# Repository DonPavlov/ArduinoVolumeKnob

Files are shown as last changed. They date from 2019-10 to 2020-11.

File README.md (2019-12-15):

This is an Arduino Pro Micro Volume Knob following the following example.

https://www.heise.de/select/make/2019/2/1556001541578799

Troubleshooting:
If your Pro Micro does not want to be programmed do the following:

Verify the correct upload port and set it in the platformio.ini file.
(Unplug the device check the which devices are under /dev/tty:
    ls /dev/tty*
And replug the device)

If programming still fails, wait while it is uploading and use something metal and connect RST and GND pin for a short while. This reset should be enough to upload the latest Arduino files onto the Board and should work now after that without an Reset.

PCB Layout
------------------

The PCB itself was designed in KiCaD and has the following design:

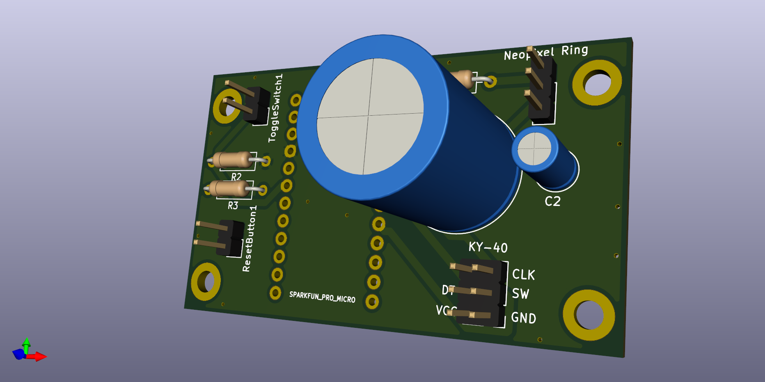
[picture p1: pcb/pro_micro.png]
3dView

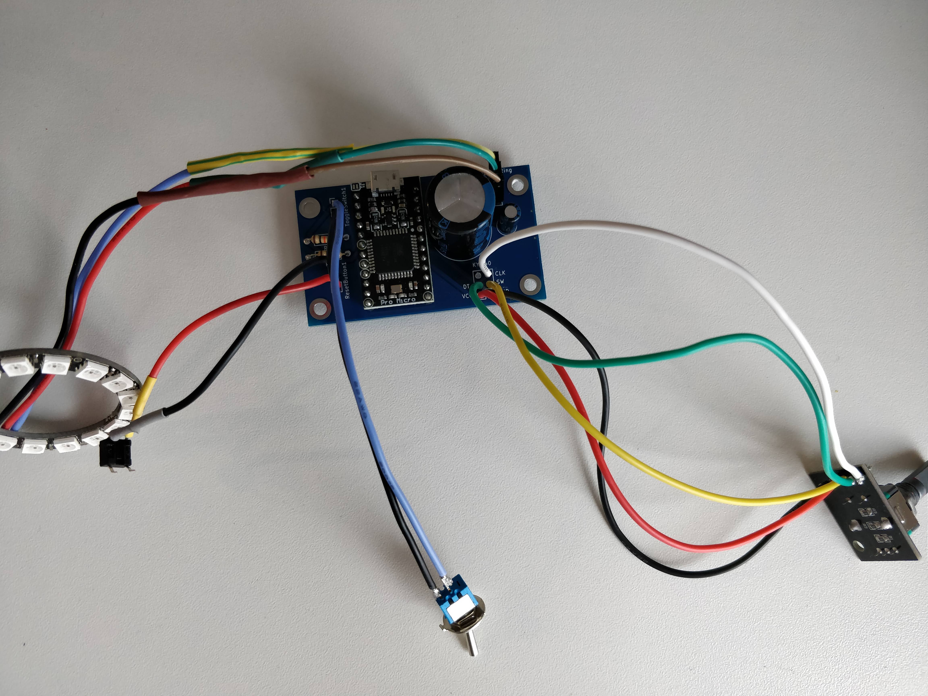
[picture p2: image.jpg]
soldered

schematic

It uses additional features of a possible reset button.
And a free toggle Button to connect and do interesting stuff. (Select in grub the used os to boot or other such things)

TODO
-------------------

* Implement functionality to select windows in grub (arrow down, arrow down, enter) after device was switched on after 5 seconds it will trigger (depends on grub timeout)
    * Do this only if the switch was flipped into the windows position
* Better documentation

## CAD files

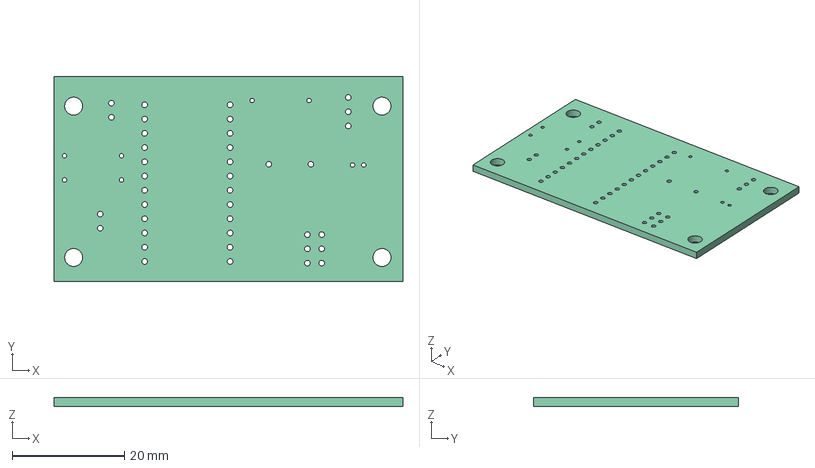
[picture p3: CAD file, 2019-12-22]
pcb/pcbstepup.FCStd
62.2 x 36.5 x 1.60 mm

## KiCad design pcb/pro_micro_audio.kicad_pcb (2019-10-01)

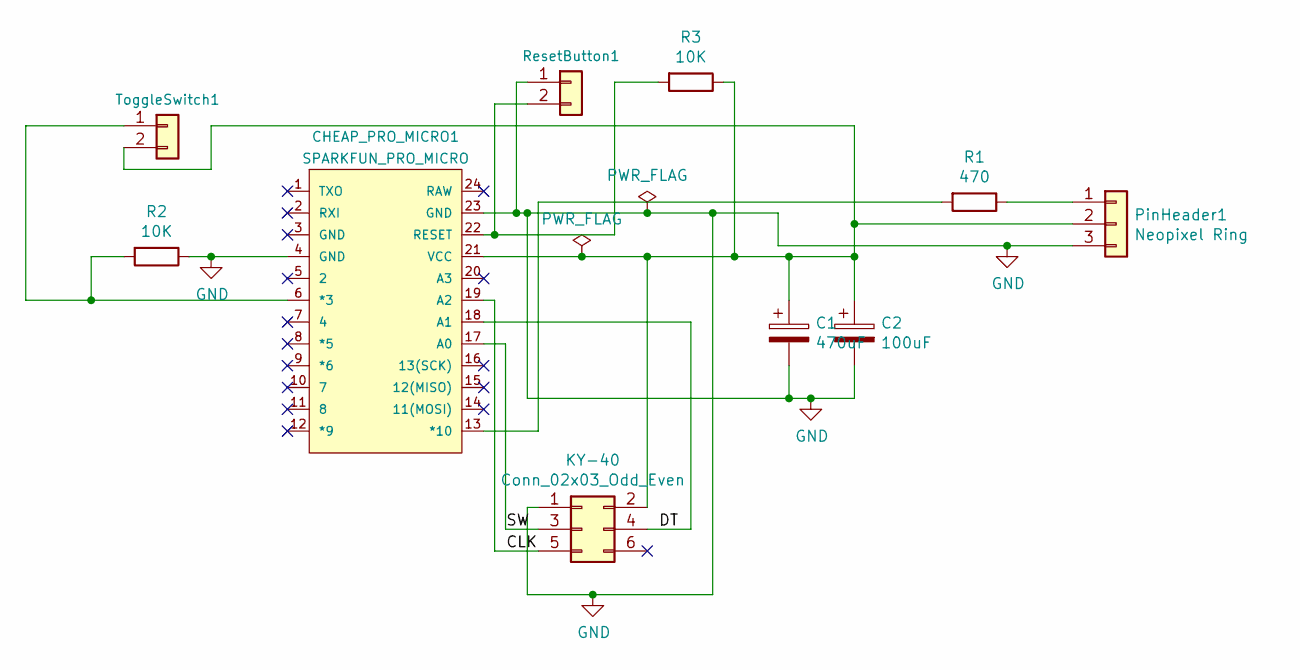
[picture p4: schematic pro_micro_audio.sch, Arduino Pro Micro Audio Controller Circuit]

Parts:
C1: 470uF; C_Radial_D16.0mm_H25.0mm_P7.50mm
C2: 100uF; C_Radial_D5.0mm_H11.0mm_P2.00mm
CHEAP_PRO_MICRO1: SPARKFUN_PRO_MICRO
KY-40: Conn_02x03_Odd_Even; PinHeader_2x03_P2.54mm_Vertical
PinHeader1: Neopixel Ring; PinHeader_1x03_P2.54mm_Vertical
R1: 470; R_Axial_DIN0207_L6.3mm_D2.5mm_P10.16mm_Horizontal
R2, R3: 10K; R_Axial_DIN0207_L6.3mm_D2.5mm_P10.16mm_Horizontal
ResetButton1: Connector_Generic:Conn_01x02; PinHeader_1x02_P2.54mm_Vertical
ToggleSwitch1: Connector_Generic:Conn_01x02; PinHeader_1x02_P2.54mm_Vertical

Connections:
/CLK: CHEAP_PRO_MICRO1.19 (A2), KY-40.5
/DT: CHEAP_PRO_MICRO1.18 (A1), KY-40.4
/SW: CHEAP_PRO_MICRO1.17 (A0), KY-40.3
GND: C1.2, C2.2, CHEAP_PRO_MICRO1.4 (GND), CHEAP_PRO_MICRO1.23 (GND), KY-40.1, PinHeader1.3, R2.1, ResetButton1.1
unnamed: C1.1, C2.1, CHEAP_PRO_MICRO1.21 (VCC), KY-40.2, PinHeader1.2, R3.1, ToggleSwitch1.2
unnamed: CHEAP_PRO_MICRO1.6 (*3), R2.2, ToggleSwitch1.1
unnamed: CHEAP_PRO_MICRO1.13 (*10), R1.2
unnamed: CHEAP_PRO_MICRO1.22 (RESET), R3.2, ResetButton1.2
unnamed: PinHeader1.1, R1.1

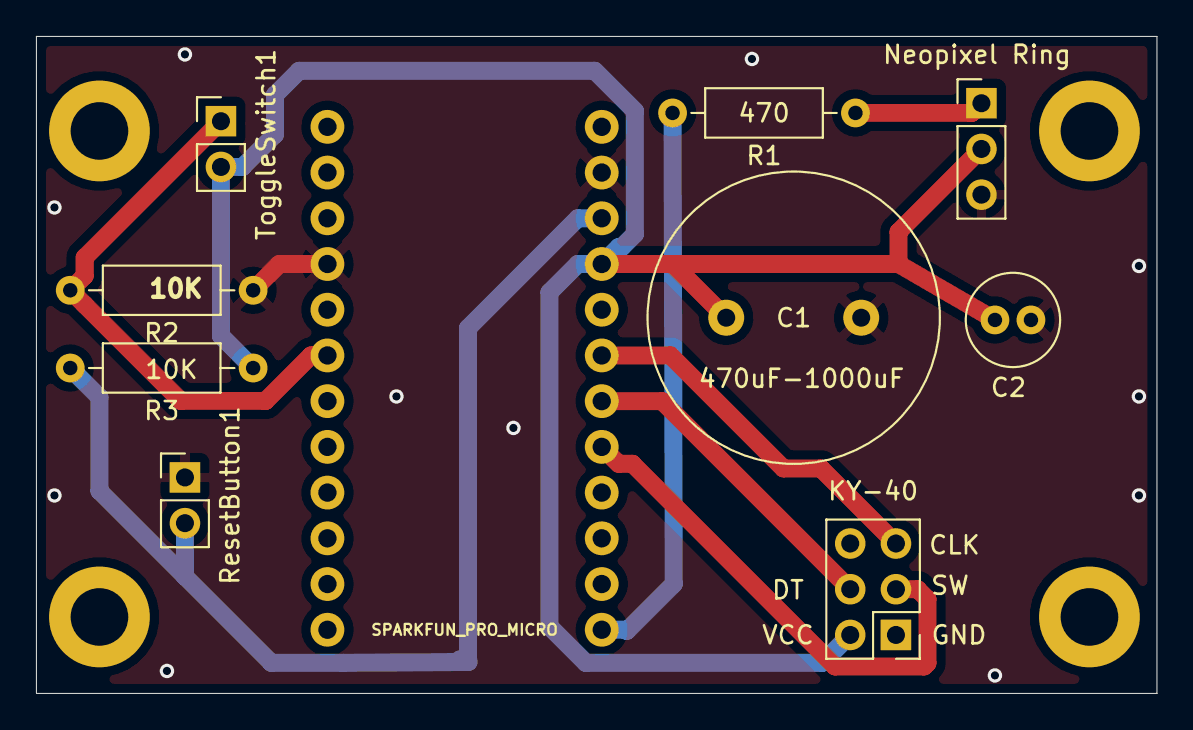
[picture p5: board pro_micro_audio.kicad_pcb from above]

Board: 2 copper layers, 62.2 x 36.5 mm, 10 parts (0 on the bottom side), 9 nets.

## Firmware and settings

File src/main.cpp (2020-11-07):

#include <Adafruit_NeoPixel.h>
#include <Arduino.h>
#include <ClickEncoder.h>
#include <HID-Project.h>
#include <TimerOne.h>

#define TOGGLE_PIN 3
#define LIGHT_PIN 10
#define NR_OF_PIXELS 16
#define TIMEOUT_VIBRA_MS 50
#define TIMEOUT_LIGHTS_MS 600

#define DEBUG 1
Adafruit_NeoPixel strip(NR_OF_PIXELS, LIGHT_PIN, NEO_GRB + NEO_KHZ800);
const uint32_t WHITE = strip.Color(255, 255, 255);
const uint32_t RED = strip.Color(255, 0, 0);
const uint32_t GREEN = strip.Color(0, 255, 0);
const uint32_t BLUE = strip.Color(0, 0, 255);
const uint32_t BLACK = 0;
const uint32_t PINK = strip.Color(255, 0, 255);
const uint32_t DANGER_GREEN = strip.Color(51, 255, 51);
const uint32_t YELLOW = strip.Color(240, 240, 0);
const uint32_t ORANGE = strip.Color(255, 128, 0);
const uint32_t TURKOISE = strip.Color(101, 240, 240);

ClickEncoder encoder(A1, A2, A0);
unsigned long lastInteraction = 0;
int16_t intensity = 0;

void setColor(uint32_t c);
void volumeChange(uint16_t key, uint32_t color);
void setup();
void loop();
void grubSelector();
void colorWipe(uint32_t c, uint8_t wait);
void setColorState(uint8_t state);
void rainbow(uint8_t wait);
void rainbowCycle(uint8_t wait);
void theaterChase(uint32_t c, uint8_t wait);
void theaterChaseRainbow(uint8_t wait);
uint32_t Wheel(byte WheelPos);
void startShow(uint8_t i);

void setup() {
  delay(3000);
  lastInteraction = 0;
  intensity = 0;
  strip.begin();
  strip.show();
  setColor(BLACK);
  // disable leds because we only need neopixels
  pinMode(LED_BUILTIN_TX, INPUT);
  pinMode(LED_BUILTIN_RX, INPUT);

  pinMode(TOGGLE_PIN, INPUT);
#ifdef DEBUG
  Serial.begin(115200);
  uint8_t val1 = digitalRead(TOGGLE_PIN);
  Serial.println(val1);
#endif
  Timer1.stop();
  Timer1.detachInterrupt();
  delay(100);
  // uint8_t val = digitalRead(TOGGLE_PIN);
  // if(val == 1) {
  //   delay(5000);  // wait 15 seconds before it is usable
  //   // grubSelector();   // currently not needed thanks to Linux only boot
  // }

  Timer1.initialize(1000);
  Timer1.attachInterrupt([] { encoder.service(); });

  Consumer.begin();
}

uint8_t colorState = 0u;
uint8_t debugval = 0u;
uint8_t count = 0;

uint8_t showType = 0;

void loop() {
  int16_t value = encoder.getValue();
  if (value != 0) {
    if (value < 0) {
      intensity = max(1, min(intensity + 1, 10));
      volumeChange(MEDIA_VOLUME_UP, GREEN);
#ifdef DEBUG
      Serial.println("VolUp");
#endif
    } else {
      intensity = min(-1, max(intensity - 1, -10));
      volumeChange(MEDIA_VOLUME_DOWN, RED);
#ifdef DEBUG
      Serial.println("VolDown");
#endif
    }
  }

  ClickEncoder::Button b = encoder.getButton();
  if (b != ClickEncoder::Open) {
    if (b == ClickEncoder::Clicked) {
      intensity = 9;
      volumeChange(MEDIA_VOL_MUTE, BLUE);
#ifdef DEBUG
      Serial.println("Mute");
#endif
    }
  }
  //
  // LEDs nach inaktiver Zeit abschalten.
  //
  unsigned long timeDiff = millis() - lastInteraction;
  if (timeDiff > TIMEOUT_LIGHTS_MS) {
    setColor(BLACK);
    intensity = 0;
  }
}

void volumeChange(uint16_t key, uint32_t color) {
  setColor(color);
  Consumer.write(key);
  lastInteraction = millis();
}

void setColor(uint32_t c) {
  strip.setBrightness(abs(intensity) * 255 / 10);
  for (uint16_t i = 0; i < strip.numPixels(); i++) {
    strip.setPixelColor(i, c);
  }
  strip.show();
}

void grubSelector() {
  // Select Windows OS
  BootKeyboard.begin();
  BootKeyboard.write(KEY_DOWN_ARROW);
  delay(100);
  BootKeyboard.write(KEY_DOWN_ARROW);
  delay(100);
  BootKeyboard.write(KEY_ENTER);
  delay(100);

  BootKeyboard.end();
}

void colorWipe(uint32_t c, uint8_t wait) {
  for (uint16_t i = 0; i < strip.numPixels(); i++) {
    strip.setPixelColor(i, c);
    strip.show();
    delay(wait);
  }
}

void setColorState(uint8_t state) {
  switch (state) {
    case 0:
      setColor(WHITE);
      break;
    case 1:
      setColor(RED);
      break;
    case 2:
      setColor(GREEN);
      break;
    case 3:
      setColor(BLUE);
      break;
    case 4:
      setColor(PINK);
      break;
    case 5:
      setColor(DANGER_GREEN);
      break;
    case 6:
      setColor(YELLOW);
      break;
    case 7:
      setColor(ORANGE);
      break;
    case 8:
      setColor(TURKOISE);
      break;
    default:
      break;
  }
}

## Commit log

2019-09-11 disable rx tx leds
2019-09-12 update led number
2019-09-14 fix timerone error with led not stopping
    [main.cpp]
2019-09-14 remove vibration motor traces completely
    [main.cpp]
2019-09-28 update for latest pcb changes
2019-10-01 add kicad files
    [pro_micro_audio-B_Cu.gbr, pro_micro_audio-B_Mask.gbr, pro_micro_audio-B_SilkS.gbr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]
2019-12-22 add christmas color mode
    [cad_models.FCStd, pcbstepup.FCStd]
2019-12-22 remove unused cad files
    [cad_models.FCStd]
